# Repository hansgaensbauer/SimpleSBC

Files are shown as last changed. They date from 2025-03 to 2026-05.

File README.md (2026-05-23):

# SimpleSBC
A simple, open source SBC built around the STM32MP1

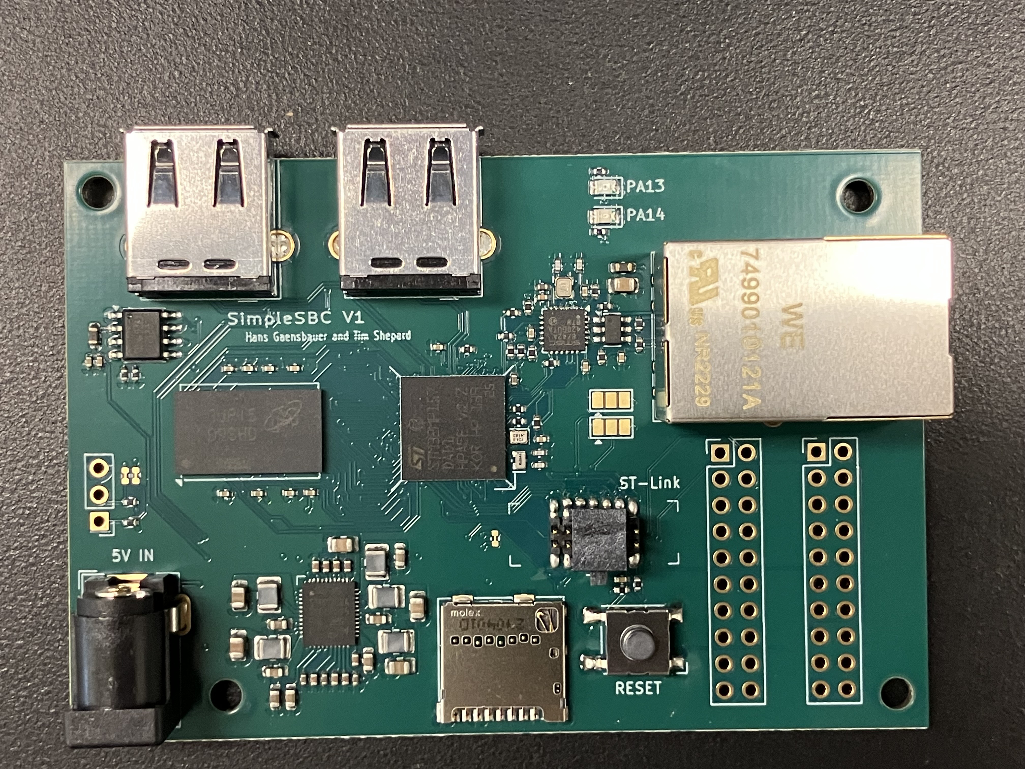
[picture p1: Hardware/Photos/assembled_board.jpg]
A photo of the assembled board


## Getting Started
1. `git clone` this repository
2. Run `git submodule init` and `git submodule update --recursive` to get Yocto and layers
3. Install dependencies:
   ```
   sudo apt update
   sudo apt upgrade
   sudo apt install -y bc build-essential chrpath cpio diffstat gawk git texinfo wget gdisk python3 python3-pip
   ```
4. Run `source poky/oe-init-build-env build-simplesbc` to set up the environment
5. Run `bitbake custom-image` to build! This could take a while
6. After the build, use yocto\copy_sd.sh to set up an SD card. You may need to change the device name in the script.
7. Connect an ST-Link or other USB-Serial converter, and plug in power.
8. Enjoy linux! The default meta-custom layer includes python and some python libraries. 

## Related Projects
- [Linux-Keyer](https://github.com/hansgaensbauer/Linux-Keyer/tree/main): A real-time linux based CW keyer built around SimpleSBC

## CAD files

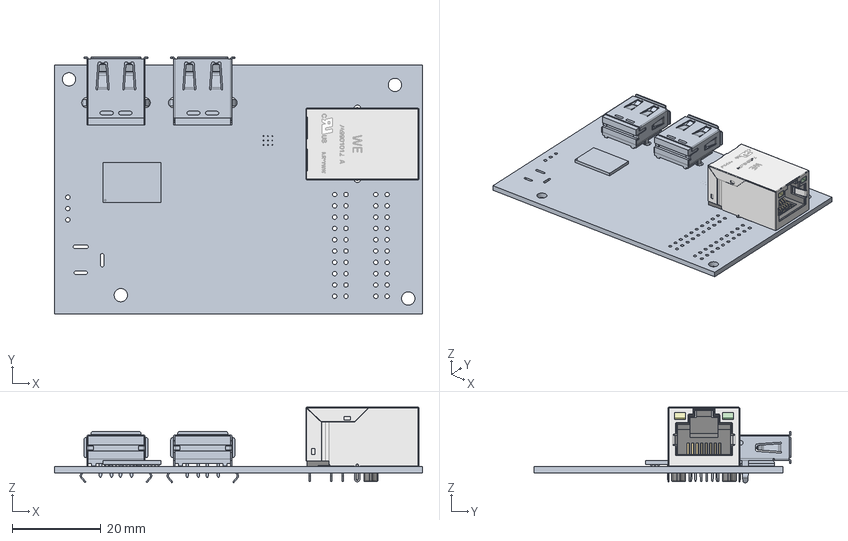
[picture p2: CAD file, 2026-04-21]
Hardware/simpleSBC.step
82.7 x 57.8 x 17.0 mm
USB_A_Molex_67643_Horizontal x 2
BGA-96_9.0x13.0mm_Layout2x3x16_P0.8mm
simpleSBC_PCB

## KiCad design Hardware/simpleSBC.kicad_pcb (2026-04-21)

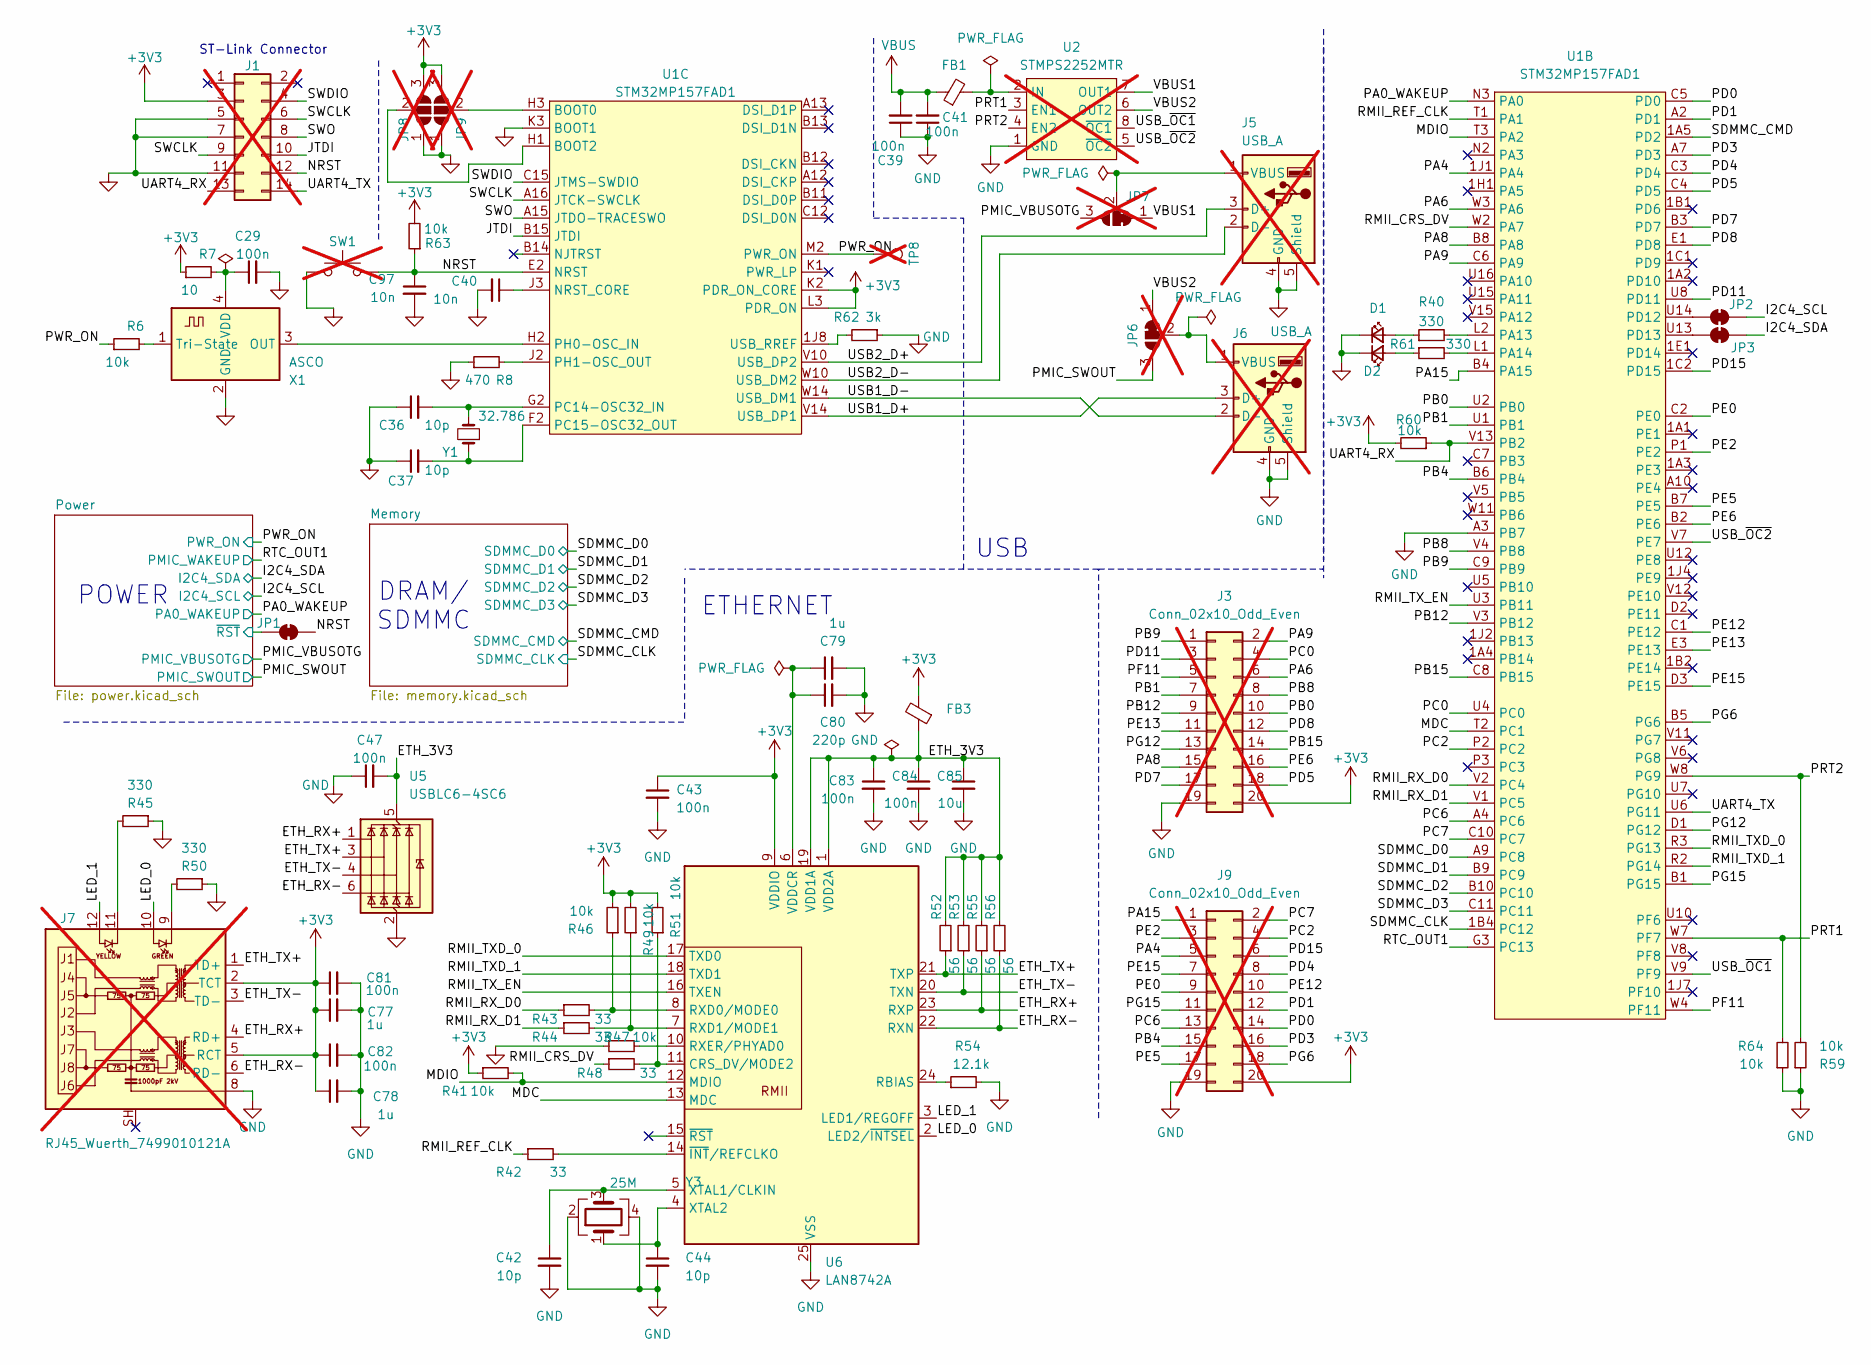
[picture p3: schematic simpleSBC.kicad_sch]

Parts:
C29, C39, C41, C43, C47, C81, C82, C83, C84: 100n; C_0402_1005Metric; JLCPCB Part # C1525
C36, C37, C42, C44: 10p; C_0402_1005Metric; JLCPCB Part # C32949
C40, C97: 10n; C_0402_1005Metric; JLCPCB Part # C15195
C77, C78, C79: 1u; C_0402_1005Metric; JLCPCB Part # C52923
C80: 220p; C_0402_1005Metric; JLCPCB Part # C1530
C85: 10u; C_0805_2012Metric; JLCPCB Part # C15850
D1: LED_Small; LED_0805_2012Metric; JLCPCB Part # C2296
D2: LED_Small; LED_0805_2012Metric; JLCPCB Part # C2297
FB1, FB3: FerriteBead_Small; L_0603_1608Metric; JLCPCB Part # C1002
J1: Conn_02x07_Odd_Even; PinHeader_2x7_P1.27mm_SMD; not fitted
J3, J9: Conn_02x10_Odd_Even; PinHeader_2x10_P2.54mm_Vertical; not fitted
J5, J6: USB_A; USB_A_Molex_67643_Horizontal; not fitted
J7: RJ45_Wuerth_7499010121A; RJ45_Wuerth_7499010121A_Horizontal; not fitted
JP1, JP2, JP3: SolderJumper_2_Bridged; Jumper_0402_Short
JP6, JP7: SolderJumper_3_Bridged12; SolderJumper-3_P1.3mm_Bridged2Bar12_Pad1.0x1.5mm; not fitted
JP8, JP9: SolderJumper_3_Open; SolderJumper-3_P1.3mm_Open_Pad1.0x1.5mm; not fitted
R6, R41, R46, R47, R49, R51, R59, R60, R63, R64: 10k; R_0402_1005Metric; JLCPCB Part # C25744
R7: 10; R_0402_1005Metric; JLCPCB Part # C25077
R8: 470; R_0402_1005Metric; JLCPCB Part # C25117
R40, R45, R50, R61: 330; R_0402_1005Metric; JLCPCB Part # C25104
R42, R43, R44, R48: 33; R_0402_1005Metric; JLCPCB Part # C25105
R52, R53, R55, R56: 56; R_0402_1005Metric; JLCPCB Part # C25127
R54: 12.1k; R_0402_1005Metric; JLCPCB Part # C25863
R62: 3k; R_0402_1005Metric; JLCPCB Part # C881171
SW1: SW_Push; SW_SPST_Omron_B3FS-101xP; not fitted
TP8: TestPoint; TestPoint_Pad_D1.0mm; not fitted
U1: STM32MP157FAD1; TFBGA257; JLCPCB Part # C1236719
U2: STMPS2252MTR; SOIC-8_3.9x4.9mm_P1.27mm; JLCPCB Part # C2680426; not fitted
U5: USBLC6-4SC6; SOT-23-6; JLCPCB Part # C111212
U6: LAN8742A; VQFN-24-1EP_4x4mm_P0.5mm_EP2.5x2.5mm_ThermalVias; JLCPCB Part # C220794
X1: ASCO; Oscillator_SMD_Abracon_ASCO-4Pin_1.6x1.2mm; JLCPCB Part # C19078199
Y1: 32.786; Crystal_SMD_MicroCrystal_CM9V-T1A-2Pin_1.6x1.0mm; JLCPCB Part # C5341287
Y3: 25M; Crystal_2.00x1.60mm; MPN 402F2501XIAR; JLCPCB Part # C127895

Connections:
+3V3: C43.1, C77.1, C78.1, C81.1, C82.1, FB3.2, J1.3, J3.20, J7.2 (TCT), J7.5 (RCT), J9.20, JP8.3 (B), JP9.3 (B), R7.1, R41.1, R46.2, R49.2, R51.2, R60.2, R63.2, U1.K2 (PDR_ON_CORE), U1.L3 (PDR_ON), U6.9 (VDDIO); also elsewhere on the board
/ETH_3V3: C47.2, C83.1, C84.1, C85.1, FB3.1, R52.2, R53.2, R55.2, R56.2, U5.5 (VBUS), U6.1 (VDD2A), U6.19 (VDD1A)
/ETH_RX+: J7.4 (RD+), R55.1, U5.1 (I/O1), U6.23 (RXP)
/ETH_RX-: J7.6 (RD-), R56.1, U5.6 (I/O4), U6.22 (RXN)
/ETH_TX+: J7.1 (TD+), R52.1, U5.3 (I/O2), U6.21 (TXP)
/ETH_TX-: J7.3 (TD-), R53.1, U5.4 (I/O3), U6.20 (TXN)
/I2C4_SCL: JP2.2 (B); also elsewhere on the board
/I2C4_SDA: JP3.2 (B); also elsewhere on the board
/JTDI: J1.10, U1.B15 (JTDI)
/LED_0: J7.10, U6.2 (LED2/~INTSEL)
/LED_1: J7.12, U6.3 (LED1/REGOFF)
/MDC: U1.T2 (PC1), U6.13 (MDC)
/MDIO: R41.2, U1.T3 (PA2), U6.12 (MDIO)
/NRST: C97.1, J1.12, JP1.2 (B), R63.1, SW1.2, U1.E2 (NRST)
/PA0_WAKEUP: U1.N3 (PA0); also elsewhere on the board
/PA4: J9.5, U1.1J1 (PA4)
/PA6: J3.6, U1.W3 (PA6)
/PA8: J3.15, U1.B8 (PA8)
/PA9: J3.2, U1.C6 (PA9)
/PA15: J9.1, U1.B4 (PA15)
/PB0: J3.10, U1.U2 (PB0)
/PB1: J3.7, U1.U1 (PB1)
/PB4: J9.15, U1.B6 (PB4)
/PB8: J3.8, U1.V4 (PB8)
/PB9: J3.1, U1.C9 (PB9)
/PB12: J3.9, U1.V3 (PB12)
/PB15: J3.14, U1.C8 (PB15)
/PC0: J3.4, U1.U4 (PC0)
/PC2: J9.4, U1.P2 (PC2)
/PC6: J9.13, U1.A4 (PC6)
/PC7: J9.2, U1.C10 (PC7)
/PD0: J9.14, U1.C5 (PD0)
/PD1: J9.12, U1.A2 (PD1)
/PD3: J9.16, U1.A7 (PD3)
/PD4: J9.8, U1.C3 (PD4)
/PD5: J3.18, U1.C4 (PD5)
/PD7: J3.17, U1.B3 (PD7)
/PD8: J3.12, U1.E1 (PD8)
/PD11: J3.3, U1.U8 (PD11)
/PD15: J9.6, U1.1C2 (PD15)
/PE0: J9.9, U1.C2 (PE0)
/PE2: J9.3, U1.P1 (PE2)
/PE5: J9.17, U1.B7 (PE5)
/PE6: J3.16, U1.B2 (PE6)
/PE12: J9.10, U1.C1 (PE12)
/PE13: J3.11, U1.E3 (PE13)
/PE15: J9.7, U1.D3 (PE15)
/PF11: J3.5, U1.W4 (PF11)
/PG6: J9.18, U1.B5 (PG6)
/PG12: J3.13, U1.D1 (PG12)
/PG15: J9.11, U1.B1 (PG15)
/PMIC_SWOUT: JP6.3 (B); also elsewhere on the board
/PMIC_VBUSOTG: JP7.3 (B); also elsewhere on the board
/PRT1: R64.2, U1.W7 (PF7), U2.3 (EN1)
/PRT2: R59.2, U1.W8 (PG9), U2.4 (EN2)
/PWR_ON: R6.1, TP8.1, U1.M2 (PWR_ON); also elsewhere on the board
/Power/~RST: JP1.1 (A); also elsewhere on the board
/RMII_CRS_DV: R48.1, U1.W2 (PA7)
/RMII_REF_CLK: R42.1, U1.T1 (PA1)
/RMII_RX_D0: R43.1, U1.V2 (PC4)
/RMII_RX_D1: R44.1, U1.V1 (PC5)
/RMII_TXD_0: U1.R3 (PG13), U6.17 (TXD0)
/RMII_TXD_1: U1.R2 (PG14), U6.18 (TXD1)
/RMII_TX_EN: U1.U3 (PB11), U6.16 (TXEN)
/RTC_OUT1: U1.G3 (PC13); also elsewhere on the board
/SDMMC_CLK: U1.1B4 (PC12); also elsewhere on the board
/SDMMC_CMD: U1.1A5 (PD2); also elsewhere on the board
/SDMMC_D0: U1.A9 (PC8); also elsewhere on the board
/SDMMC_D1: U1.B9 (PC9); also elsewhere on the board
/SDMMC_D2: U1.B10 (PC10); also elsewhere on the board
/SDMMC_D3: U1.C11; also elsewhere on the board
/SWCLK: J1.6, J1.9, U1.A16 (JTCK-SWCLK)
/SWDIO: J1.4, U1.C15 (JTMS-SWDIO)
/SWO: J1.8, U1.A15 (JTDO-TRACESWO)
/UART4_RX: J1.13, R60.1, U1.V13 (PB2)
/UART4_TX: J1.14, U1.U6 (PG11)
/USB1_D+: J6.3 (D+), U1.V14 (USB_DP1)
/USB1_D-: J6.2 (D-), U1.W14 (USB_DM1)
/USB2_D+: J5.3 (D+), U1.V10 (USB_DP2)
/USB2_D-: J5.2 (D-), U1.W10 (USB_DM2)
/USB_~OC1: U1.V9 (PF9), U2.8 (~OC1)
/USB_~OC2: U1.V7 (PE7), U2.5 (~OC2)
/VBUS1: JP7.1 (A), U2.7 (OUT1)
/VBUS2: JP6.1 (A), U2.6 (OUT2)
GND: C29.2, C36.1, C37.1, C39.1, C40.2, C41.1, C42.2, C43.2, C44.2, C47.1, C77.2, C78.2, C79.2, C80.2, C81.2, C82.2, C83.2, C84.2, C85.2, C97.2, D1.1 (K), D2.1 (K), J1.5, J1.7, J1.11, J3.19, J5.4 (GND), J5.5 (Shield), J6.4 (GND), J6.5 (Shield), J7.8, J9.19, JP8.1 (A), JP9.1 (A), R8.1, R45.1, R47.1, R50.1, R54.2, R59.1, R62.1, R64.1, SW1.1, U1.A3 (PB7), U1.K3 (BOOT1), U2.1 (GND), U5.2 (GND), U6.25 (VSS), X1.2 (GND), Y3.2, Y3.4; also elsewhere on the board
unnamed: D1.2 (A), R40.1
unnamed: D2.2 (A), R61.1
unnamed: J5.1 (VBUS), JP7.2 (C)
unnamed: J6.1 (VBUS), JP6.2 (C)
unnamed: J7.9, R50.2
unnamed: J7.11, R45.2
unnamed: JP2.1 (A), U1.U14 (PD12)
unnamed: JP3.1 (A), U1.U13 (PD13)
unnamed: JP8.2 (C), U1.H1 (BOOT2)
unnamed: JP9.2 (C), U1.H3 (BOOT0)
unnamed: R40.2, U1.L2 (PA13)
unnamed: R61.2, U1.L1 (PA14)
unnamed: C40.1, U1.J3 (NRST_CORE)
unnamed: C36.2, U1.G2 (PC14-OSC32_IN), Y1.2
unnamed: C37.2, U1.F2 (PC15-OSC32_OUT), Y1.1
unnamed: U1.H2 (PH0-OSC_IN), X1.3 (OUT)
unnamed: R8.2, U1.J2 (PH1-OSC_OUT)
unnamed: R62.2, U1.1J8 (USB_RREF)
unnamed: FB1.2, U2.2 (IN)
unnamed: R48.2, R51.1, U6.11 (CRS_DV/MODE2)
unnamed: R54.1, U6.24 (RBIAS)
unnamed: R43.2, R46.1, U6.8 (RXD0/MODE0)
unnamed: R44.2, R49.1, U6.7 (RXD1/MODE1)
unnamed: R47.2, U6.10 (RXER/PHYAD0)
unnamed: C79.1, C80.1, U6.6 (VDDCR)
unnamed: C42.1, U6.5 (XTAL1/CLKIN), Y3.3
unnamed: C44.1, U6.4 (XTAL2), Y3.1
unnamed: R42.2, U6.14 (~INT/REFCLKO)
unnamed: R6.2, X1.1 (Tri-State)
unnamed: C29.1, R7.2, X1.4 (VDD)
VBUS: C39.2, C41.2, FB1.1; also elsewhere on the board

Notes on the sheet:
USB
DRAM/ SDMMC
POWER
ETHERNET
ST-Link Connector

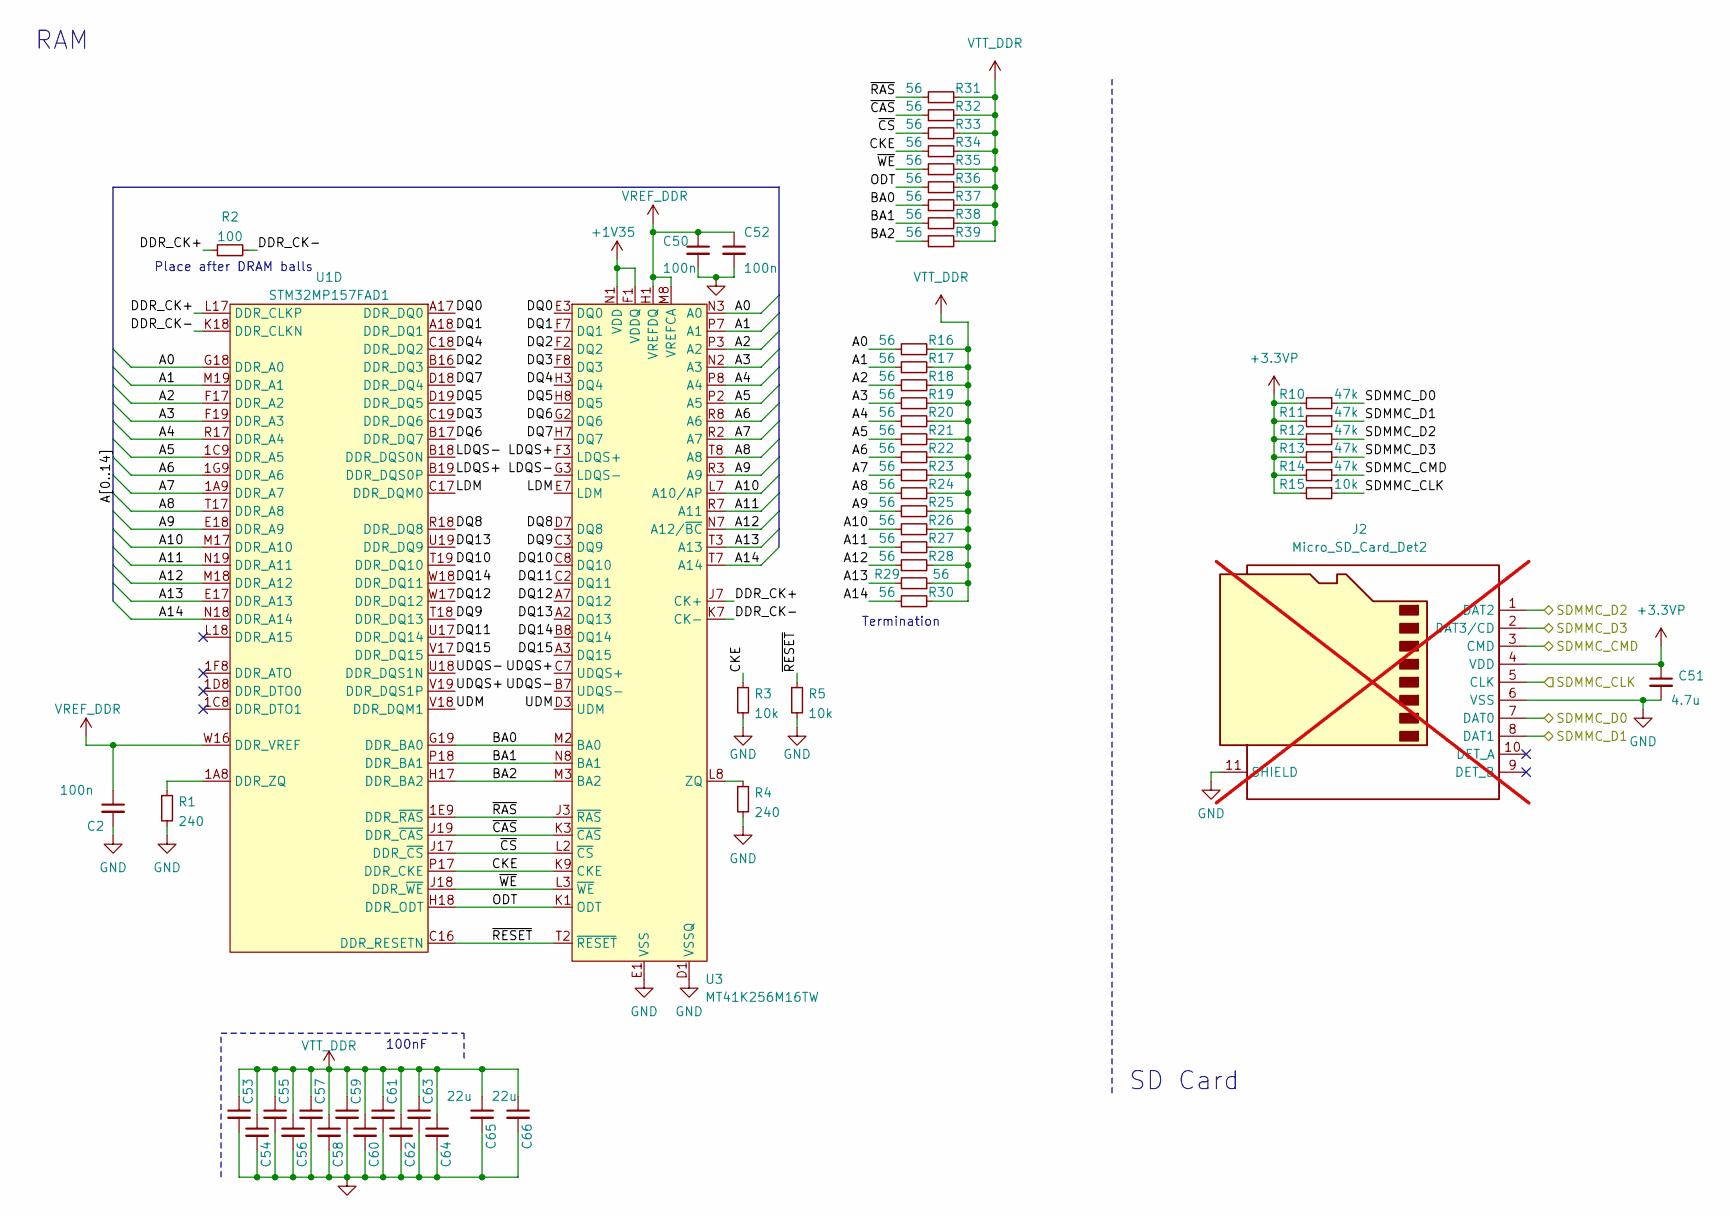
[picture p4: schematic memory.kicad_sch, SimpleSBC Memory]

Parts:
C2, C50, C52, C53, C54, C55, C56, C57, C58, C59, C60, C61, C62, C63, C64: 100n; C_0402_1005Metric; JLCPCB Part # C1525
C51: 4.7u; C_0402_1005Metric; JLCPCB Part # C23733
C65, C66: 22u; C_0805_2012Metric; JLCPCB Part # C45783
J2: Micro_SD_Card_Det2; microSD_HC_Molex_104031-0811; not fitted
R1, R4: 240; R_0402_1005Metric; JLCPCB Part # C208835
R2: 100; R_0402_1005Metric; JLCPCB Part # C25076
R3, R5, R15: 10k; R_0402_1005Metric; JLCPCB Part # C25744
R10, R11, R12, R13, R14: 47k; R_0402_1005Metric; JLCPCB Part # C25792
R16, R17, R18, R19, R20, R21, R22, R23, R24, R25, R26, R27, R28, R29, R30, R31, R32, R33, R34, R35, R36, R37, R38, R39: 56; R_0402_1005Metric; JLCPCB Part # C25127
U1: STM32MP157FAD1; TFBGA257; JLCPCB Part # C1236719
U3: MT41K256M16TW; BGA-96_9.0x13.0mm_Layout2x3x16_P0.8mm; JLCPCB Part # C253882

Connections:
+1V35: U3.A1 (VDDQ), U3.A8 (VDDQ), U3.B2 (VDD), U3.C1 (VDDQ), U3.C9 (VDDQ), U3.D2 (VDDQ), U3.D9 (VDD), U3.E9 (VDDQ), U3.F1 (VDDQ), U3.G7 (VDD), U3.H2 (VDDQ), U3.H9 (VDDQ), U3.K2 (VDD), U3.K8 (VDD), U3.N1 (VDD), U3.N9 (VDD), U3.R1 (VDD), U3.R9 (VDD); also elsewhere on the board
+3.3VP: C51.1, J2.4 (VDD), R10.2, R11.2, R12.2, R13.2, R14.2, R15.2; also elsewhere on the board
/Memory/A0: R16.1, U1.G18 (DDR_A0), U3.N3 (A0)
/Memory/A1: R17.1, U1.M19 (DDR_A1), U3.P7 (A1)
/Memory/A2: R18.1, U1.F17 (DDR_A2), U3.P3 (A2)
/Memory/A3: R19.1, U1.F19 (DDR_A3), U3.N2 (A3)
/Memory/A4: R20.1, U1.R17 (DDR_A4), U3.P8 (A4)
/Memory/A5: R21.1, U1.1C9 (DDR_A5), U3.P2 (A5)
/Memory/A6: R22.1, U1.1G9 (DDR_A6), U3.R8 (A6)
/Memory/A7: R23.1, U1.1A9 (DDR_A7), U3.R2 (A7)
/Memory/A8: R24.1, U1.T17 (DDR_A8), U3.T8 (A8)
/Memory/A9: R25.1, U1.E18 (DDR_A9), U3.R3 (A9)
/Memory/A10: R26.1, U1.M17 (DDR_A10), U3.L7 (A10/AP)
/Memory/A11: R27.1, U1.N19 (DDR_A11), U3.R7 (A11)
/Memory/A12: R28.1, U1.M18 (DDR_A12), U3.N7 (A12/~BC)
/Memory/A13: R29.2, U1.E17 (DDR_A13), U3.T3 (A13)
/Memory/A14: R30.1, U1.N18 (DDR_A14), U3.T7 (A14)
/Memory/BA0: R37.1, U1.G19 (DDR_BA0), U3.M2 (BA0)
/Memory/BA1: R38.1, U1.P18 (DDR_BA1), U3.N8 (BA1)
/Memory/BA2: R39.1, U1.H17 (DDR_BA2), U3.M3 (BA2)
/Memory/CKE: R3.1, R34.1, U1.P17 (DDR_CKE), U3.K9 (CKE)
/Memory/DDR_CK+: R2.1, U1.L17 (DDR_CLKP), U3.J7 (CK+)
/Memory/DDR_CK-: R2.2, U1.K18 (DDR_CLKN), U3.K7 (CK-)
/Memory/DQ0: U1.A17 (DDR_DQ0), U3.E3 (DQ0)
/Memory/DQ1: U1.A18 (DDR_DQ1), U3.F7 (DQ1)
/Memory/DQ2: U1.B16 (DDR_DQ3), U3.F2 (DQ2)
/Memory/DQ3: U1.C19 (DDR_DQ6), U3.F8 (DQ3)
/Memory/DQ4: U1.C18 (DDR_DQ2), U3.H3 (DQ4)
/Memory/DQ5: U1.D19 (DDR_DQ5), U3.H8 (DQ5)
/Memory/DQ6: U1.B17 (DDR_DQ7), U3.G2 (DQ6)
/Memory/DQ7: U1.D18 (DDR_DQ4), U3.H7 (DQ7)
/Memory/DQ8: U1.R18 (DDR_DQ8), U3.D7 (DQ8)
/Memory/DQ9: U1.T18 (DDR_DQ13), U3.C3 (DQ9)
/Memory/DQ10: U1.T19 (DDR_DQ10), U3.C8 (DQ10)
/Memory/DQ11: U1.U17 (DDR_DQ14), U3.C2 (DQ11)
/Memory/DQ12: U1.W17 (DDR_DQ12), U3.A7 (DQ12)
/Memory/DQ13: U1.U19 (DDR_DQ9), U3.A2 (DQ13)
/Memory/DQ14: U1.W18 (DDR_DQ11), U3.B8 (DQ14)
/Memory/DQ15: U1.V17 (DDR_DQ15), U3.A3 (DQ15)
/Memory/LDM: U1.C17 (DDR_DQM0), U3.E7 (LDM)
/Memory/LDQS+: U1.B19 (DDR_DQS0P), U3.F3 (LDQS+)
/Memory/LDQS-: U1.B18 (DDR_DQS0N), U3.G3 (LDQS-)
/Memory/ODT: R36.1, U1.H18 (DDR_ODT), U3.K1 (ODT)
/Memory/UDM: U1.V18 (DDR_DQM1), U3.D3 (UDM)
/Memory/UDQS+: U1.V19 (DDR_DQS1P), U3.C7 (UDQS+)
/Memory/UDQS-: U1.U18 (DDR_DQS1N), U3.B7 (UDQS-)
/Memory/~CAS: R32.1, U1.J19 (DDR_~CAS), U3.K3 (~CAS)
/Memory/~CS: R33.1, U1.J17 (DDR_~CS), U3.L2 (~CS)
/Memory/~RAS: R31.1, U1.1E9 (DDR_~RAS), U3.J3 (~RAS)
/Memory/~RESET: R5.1, U1.C16 (DDR_RESETN), U3.T2 (~RESET)
/Memory/~WE: R35.1, U1.J18 (DDR_~WE), U3.L3 (~WE)
/SDMMC_CLK: J2.5 (CLK), R15.1; also elsewhere on the board
/SDMMC_CMD: J2.3 (CMD), R14.1; also elsewhere on the board
/SDMMC_D0: J2.7 (DAT0), R10.1; also elsewhere on the board
/SDMMC_D1: J2.8 (DAT1), R11.1; also elsewhere on the board
/SDMMC_D2: J2.1 (DAT2), R12.1; also elsewhere on the board
/SDMMC_D3: J2.2 (DAT3/CD), R13.1; also elsewhere on the board
GND: C2.2, C50.2, C51.2, C52.2, C53.2, C54.2, C55.2, C56.2, C57.2, C58.2, C59.2, C60.2, C61.2, C62.2, C63.2, C64.2, C65.2, C66.2, J2.6 (VSS), J2.11 (SHIELD), R1.2, R3.2, R4.2, R5.2, U3.A9 (VSS), U3.B1 (VSSQ), U3.B3 (VSS), U3.B9 (VSSQ), U3.D1 (VSSQ), U3.D8 (VSSQ), U3.E1 (VSS), U3.E2 (VSSQ), U3.E8 (VSSQ), U3.F9 (VSSQ), U3.G1 (VSSQ), U3.G8 (VSS), U3.G9 (VSSQ), U3.J2 (VSS), U3.J8 (VSS), U3.M1 (VSS), U3.M9 (VSS), U3.P1 (VSS), U3.P9 (VSS), U3.T1 (VSS), U3.T9 (VSS); also elsewhere on the board
unnamed: R1.1, U1.1A8 (DDR_ZQ)
unnamed: R4.1, U3.L8 (ZQ)
VREF_DDR: C2.1, C50.1, C52.1, U1.W16 (DDR_VREF), U3.H1 (VREFDQ), U3.M8 (VREFCA); also elsewhere on the board
VTT_DDR: C53.1, C54.1, C55.1, C56.1, C57.1, C58.1, C59.1, C60.1, C61.1, C62.1, C63.1, C64.1, C65.1, C66.1, R16.2, R17.2, R18.2, R19.2, R20.2, R21.2, R22.2, R23.2, R24.2, R25.2, R26.2, R27.2, R28.2, R29.1, R30.2, R31.2, R32.2, R33.2, R34.2, R35.2, R36.2, R37.2, R38.2, R39.2; also elsewhere on the board

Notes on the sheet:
RAM
SD Card
100nF
Place after DRAM balls
Termination

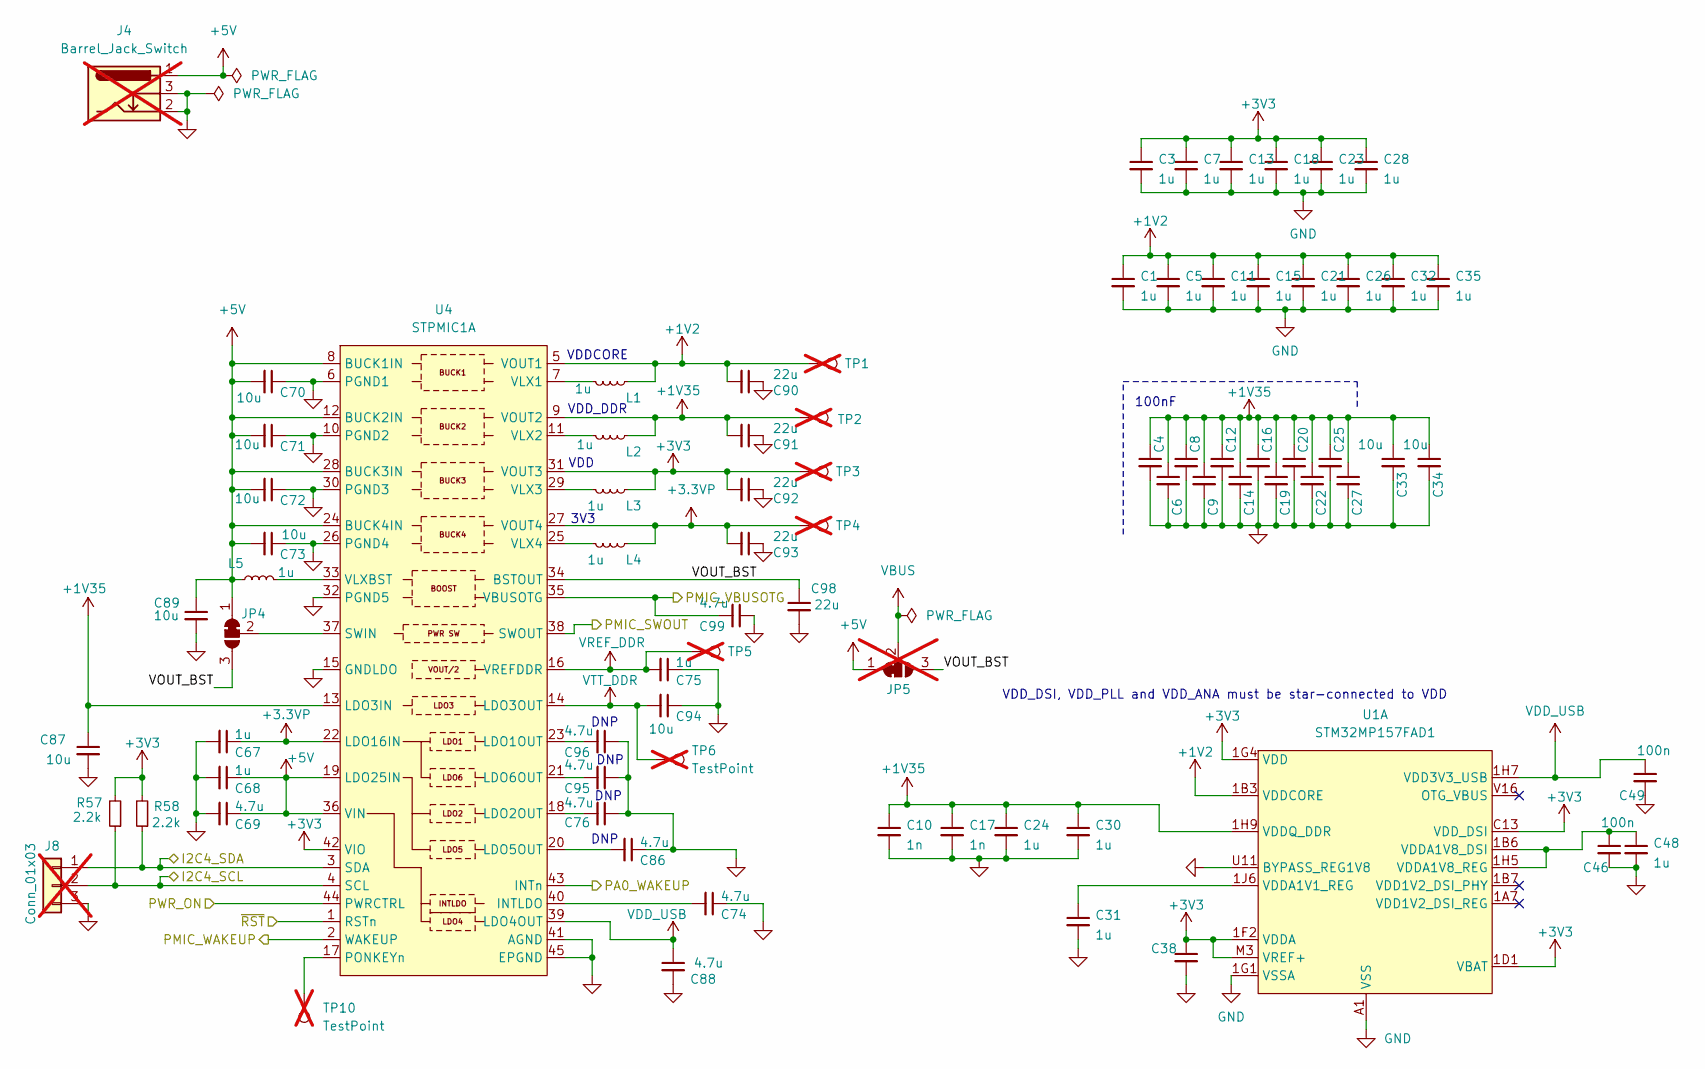
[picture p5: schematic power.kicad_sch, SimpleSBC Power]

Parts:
C1, C3, C5, C7, C11, C13, C15, C18, C21, C23, C24, C26, C28, C30, C31, C32, C35, C38, C48, C67, C68, C75: 1u; C_0402_1005Metric; JLCPCB Part # C52923
C4, C6, C8, C9, C12, C14, C16, C19, C20, C22, C25, C27, C46, C49: 100n; C_0402_1005Metric; JLCPCB Part # C1525
C10, C17: 1n; C_0402_1005Metric; JLCPCB Part # C1523
C33, C34: 10u; C_0805_2012Metric; JLCPCB Part # C15850
C69, C74, C76, C86, C88, C95, C96, C99: 4.7u; C_0402_1005Metric; JLCPCB Part # C23733
C70, C71, C72, C73, C87, C89, C94: 10u; C_0603_1608Metric; JLCPCB Part # C19702
C90, C91, C92, C93, C98: 22u; C_0805_2012Metric; JLCPCB Part # C45783
J4: Barrel_Jack_Switch; BarrelJack_Wuerth_6941xx301002; not fitted
J8: Conn_01x03; PinHeader_1x03_P2.54mm_Vertical; not fitted
JP4: SolderJumper_3_Bridged12; SolderJumper-3_P1.3mm_Bridged2Bar12_Pad1.0x1.5mm
JP5: SolderJumper_3_Bridged12; SolderJumper-3_P1.3mm_Bridged2Bar12_Pad1.0x1.5mm; not fitted
L1, L2, L3, L4, L5: 1u; L_1008_2520Metric; JLCPCB Part # C76795
R57, R58: 2.2k; R_0402_1005Metric; JLCPCB Part # C25879
TP1, TP2, TP3, TP4, TP5, TP6, TP10: TestPoint; TestPoint_Pad_D1.0mm; not fitted
U1: STM32MP157FAD1; TFBGA257; JLCPCB Part # C1236719
U4: STPMIC1A; WFQFN44L; JLCPCB Part # C2156050

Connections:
+1V2: C1.1, C5.1, C11.1, C15.1, C21.1, C26.1, C32.1, C35.1, C90.2, L1.2, TP1.1, U1.1B3 (VDDCORE), U1.1B5 (VDDCORE), U1.1C4 (VDDCORE), U1.1C6 (VDDCORE), U1.1D3 (VDDCORE), U1.1D5 (VDDCORE), U1.1D7 (VDDCORE), U1.1E4 (VDDCORE), U1.1E6 (VDDCORE), U1.1E8 (VDDCORE), U1.1F5 (VDDCORE), U1.1F7 (VDDCORE), U1.1G6 (VDDCORE), U1.1G8 (VDDCORE), U4.5 (VOUT1)
+1V35: C4.1, C6.1, C8.1, C9.1, C10.1, C12.1, C14.1, C16.1, C17.1, C19.1, C20.1, C22.1, C24.1, C25.1, C27.1, C30.1, C33.1, C34.1, C87.1, C91.2, L2.2, TP2.1, U1.1B9 (VDDQ_DDR), U1.1D9 (VDDQ_DDR), U1.1F9 (VDDQ_DDR), U1.1H9 (VDDQ_DDR), U4.9 (VOUT2), U4.13 (LDO3IN); also elsewhere on the board
+3.3VP: C67.1, C93.2, L4.2, TP4.1, U4.22 (LDO16IN), U4.27 (VOUT4); also elsewhere on the board
+3V3: C3.1, C7.1, C13.1, C18.1, C23.1, C28.1, C38.1, C92.2, L3.2, R57.2, R58.2, TP3.1, U1.1D1 (VBAT), U1.1E2 (VDD), U1.1F1 (VDDA), U1.1F2 (VDDA), U1.1F3 (VDD), U1.1G3 (VDD), U1.1G4 (VDD), U1.1J3 (VDD), U1.C13 (VDD_DSI), U1.M3 (VREF+), U4.31 (VOUT3), U4.42 (VIO); also elsewhere on the board
+5V: C68.1, C69.1, C70.2, C71.2, C72.2, C73.2, C89.1, J4.1, JP4.1 (A), JP5.1 (A), L5.2, U4.8 (BUCK1IN), U4.12 (BUCK2IN), U4.19 (LDO25IN), U4.24 (BUCK4IN), U4.28 (BUCK3IN), U4.36 (VIN)
/I2C4_SCL: J8.2, R57.1, U4.4 (SCL); also elsewhere on the board
/I2C4_SDA: J8.1, R58.1, U4.3 (SDA); also elsewhere on the board
/PA0_WAKEUP: U4.43 (INTn); also elsewhere on the board
/PMIC_SWOUT: U4.38 (SWOUT); also elsewhere on the board
/PMIC_VBUSOTG: C99.2, U4.35 (VBUSOTG); also elsewhere on the board
/PWR_ON: U4.44 (PWRCTRL); also elsewhere on the board
/Power/VOUT_BST: C98.1, JP4.3 (B), JP5.3 (B), U4.34 (BSTOUT)
/Power/~RST: U4.1 (RSTn); also elsewhere on the board
/RTC_OUT1: U4.2 (WAKEUP); also elsewhere on the board
GND: C1.2, C3.2, C4.2, C5.2, C6.2, C7.2, C8.2, C9.2, C10.2, C11.2, C12.2, C13.2, C14.2, C15.2, C16.2, C17.2, C18.2, C19.2, C20.2, C21.2, C22.2, C23.2, C24.2, C25.2, C26.2, C27.2, C28.2, C30.2, C31.2, C32.2, C33.2, C34.2, C35.2, C38.2, C46.2, C48.2, C49.2, C67.2, C68.2, C69.2, C70.1, C71.1, C72.1, C73.1, C74.1, C75.1, C76.1, C86.1, C87.2, C88.2, C89.2, C90.1, C91.1, C92.1, C93.1, C94.1, C95.1, C96.1, C98.2, C99.1, J4.2, J4.3, J8.3, U1.1A6 (VSS), U1.1B8 (VSS), U1.1C3 (VSS), U1.1C5 (VSS), U1.1C7 (VSS), U1.1D2 (VSS), U1.1D4 (VSS), U1.1D6 (VSS), U1.1E3 (VSS), U1.1E5 (VSS), U1.1E7 (VSS), U1.1F4 (VSS), U1.1F6 (VSS), U1.1G1 (VSSA), U1.1G2 (VSS), U1.1G5 (VSS), U1.1G7 (VSS), U1.1H2 (VSS), U1.1H3 (VSS), U1.1H4 (VSS), U1.1H6 (VSS), U1.1H8 (VSS), U1.1J5 (VSS), U1.1J9 (VSS), U1.A1 (VSS), U1.A6 (VSS), U1.A19 (VSS), U1.C14 (VSS), U1.D17 (VSS), U1.F3 (VSS), U1.F18 (VSS), U1.G1 (VSS), U1.G17 (VSS), U1.K17 (VSS), U1.K19 (VSS), U1.N1 (VSS), U1.N17 (VSS), U1.R19 (VSS), U1.U9 (VSS), U1.U11 (BYPASS_REG1V8), U1.W1 (VSS), U1.W5 (VSS), U1.W13 (VSS), U1.W19 (VSS), U4.6 (PGND1), U4.10 (PGND2), U4.15 (GNDLDO), U4.26 (PGND4), U4.30 (PGND3), U4.32 (PGND5), U4.41 (AGND), U4.45 (EPGND); also elsewhere on the board
unnamed: JP4.2 (C), U4.37 (SWIN)
unnamed: C31.1, U1.1J6 (VDDA1V1_REG)
unnamed: C46.1, C48.1, U1.1B6 (VDDA1V8_DSI), U1.1H5 (VDDA1V8_REG)
unnamed: C74.2, U4.40 (INTLDO)
unnamed: C96.2, U4.23 (LDO1OUT)
unnamed: C76.2, U4.18 (LDO2OUT)
unnamed: C86.2, U4.20 (LDO5OUT)
unnamed: C95.2, U4.21 (LDO6OUT)
unnamed: TP10.1, U4.17 (PONKEYn)
unnamed: L1.1, U4.7 (VLX1)
unnamed: L2.1, U4.11 (VLX2)
unnamed: L3.1, U4.29 (VLX3)
unnamed: L4.1, U4.25 (VLX4)
unnamed: L5.1, U4.33 (VLXBST)
VBUS: JP5.2 (C); also elsewhere on the board
VDD_USB: C49.1, C88.1, U1.1H7 (VDD3V3_USB), U4.39 (LDO4OUT)
VREF_DDR: C75.2, TP5.1, U4.16 (VREFDDR); also elsewhere on the board
VTT_DDR: C94.2, TP6.1, U4.14 (LDO3OUT); also elsewhere on the board

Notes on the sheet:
VDD
DNP
VDDCORE
100nF
3V3
VDD_DDR
VDD_DSI, VDD_PLL and VDD_ANA must be star-connected to VDD

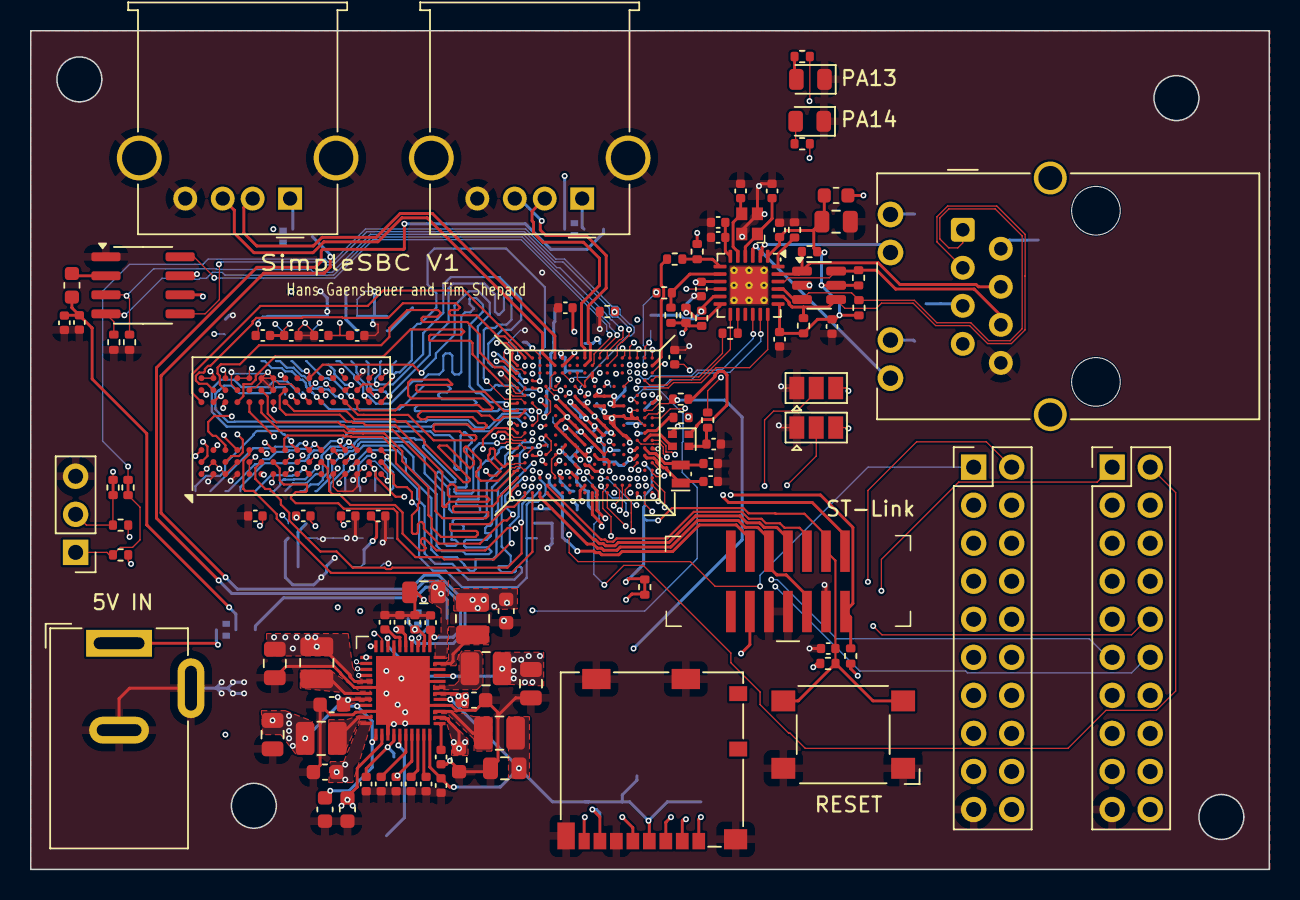
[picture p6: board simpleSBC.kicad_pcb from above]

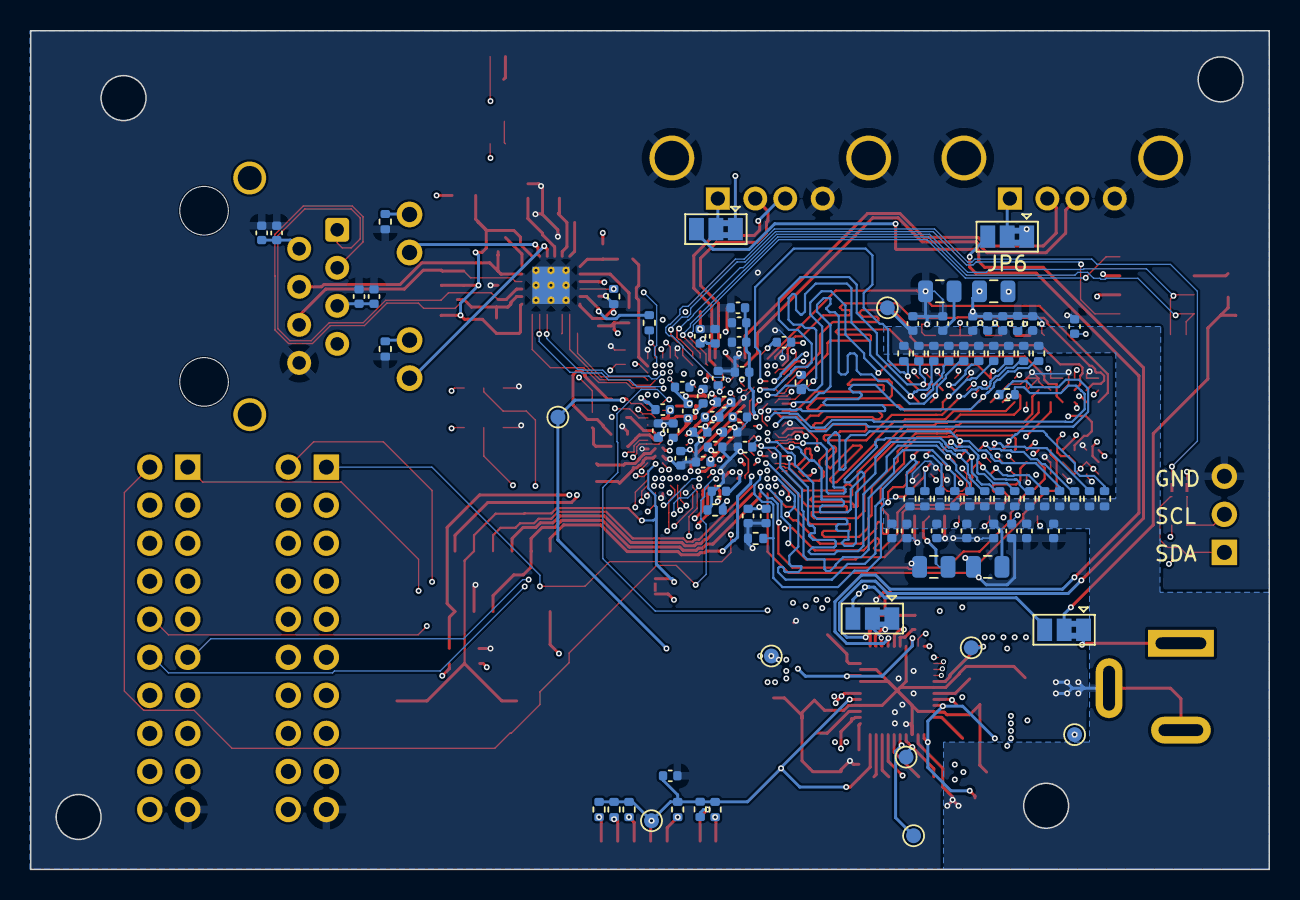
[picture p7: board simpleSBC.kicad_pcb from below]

Board: 6 copper layers, 82.7 x 56.0 mm, 206 parts (101 on the bottom side), 189 nets.

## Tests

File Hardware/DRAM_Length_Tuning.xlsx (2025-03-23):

Trace | Length
CK+ | 30.65
CK- | 30.64
A0 | 30.05
A1 | 29.96
A2 | 30.08
A3 | 29.98
A4 | 30.05
A5 | 30.04
A6 | 29.91
A7 | 29.83
A8 | 30.14
A9 | 29.86
A10 | 29.95
A11 | 29.85
A12 | 29.98
A13 | 29.92
A14 | 30.05
LDQS+ | 28.91
LDQS- | 28.91
LDM | 28.93
DQ0 | 29.04
DQ1 | 28.85
DQ2 | 29.16
DQ3 | 29.01
DQ4 | 28.93
DQ5 | 28.87
DQ6 | 29.08
DQ7 | 28.97
DQ8 | 29.06
DQ9 | 28.89
DQ10 | 29.06
DQ11 | 28.92
DQ12 | 29.03
DQ13 | 29.13
DQ14 | 29.09
DQ15 | 29.2
UDQS+ | 28.56
UDQS- | 28.56
UDM | 29
BA0 | 29.9
BA1 | 30.04
BA2 | 29.91
RASN | 29.86
CASN | 29.93
CSN | 29.93
CKE | 29.79
WEN | 29.86
ODT | 30.03

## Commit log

2022-06-21 Hardware: Add initial Hardware
    [simpleSBC.kicad_pcb, simpleSBC.kicad_sch]
2025-01-13 Add STPMIC1
    [simpleSBC.kicad_sch]
2025-02-03 Remove old files
    [memory.kicad_sch, power.kicad_sch, simpleSBC.kicad_pcb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]
2025-02-03 Create libraries and move custom symbols to project specific libraries
    [memory.kicad_sch, power.kicad_sch, simpleSBC.kicad_sch]
2025-02-04 First Draft schematic (R2)
    [memory.kicad_sch, power.kicad_sch, simpleSBC.kicad_pcb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]
2025-02-05 Add Ethernet and USB power switching
    [memory.kicad_sch, power.kicad_sch, simpleSBC.kicad_pcb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]
2025-02-05 Schematic symbol pin type fixes
    [memory.kicad_sch, power.kicad_sch, simpleSBC.kicad_sch]
2025-02-07 First pass through ST Design Checklist
    [memory.kicad_sch, power.kicad_sch, simpleSBC.kicad_pcb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]
2025-02-09 First Pass for Floorplanning
    [simpleSBC.kicad_pcb, simpleSBC.kicad_sch]
2025-03-06 First Pass Routing
    [memory.kicad_sch, power.kicad_sch, simpleSBC.kicad_pcb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]
2025-03-09 ERC/DRC Clean
    [memory.kicad_sch, power.kicad_sch, simpleSBC.kicad_pcb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]
2025-03-23 Redo DRAM Length Tuning
    [DRAM_Length_Tuning.xlsx, simpleSBC.kicad_pcb, simpleSBC.kicad_sch]
2025-03-23 Reconnect Nets after length tuning
    [DRAM_Length_Tuning.xlsx, simpleSBC.kicad_pcb, simpleSBC.kicad_sch]
2025-03-23 Add Boot selection jumpers
    [simpleSBC.kicad_pcb, simpleSBC.kicad_sch]
2025-03-24 Add USB enable pulldowns
    [power.kicad_sch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]
2025-03-24 Update .gitignore to remove cam
    [simpleSBC-B_Cu.gbr, simpleSBC-B_Mask.gbr, simpleSBC-B_Paste.gbr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]
2025-03-25 prepare for assembly
    [DRAM_Length_Tuning.xlsx, memory.kicad_sch, power.kicad_sch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]
2025-03-26 Default close jumpers and fix USB signal switching
    [simpleSBC.kicad_pcb, simpleSBC.kicad_sch]
2025-03-26 Don't track auto_saved_files
2025-07-12 submodule configuration
    [templateconf.cfg]
2025-07-15 update to scarthgap
    [templateconf.cfg]
2025-07-16 Custom device tree modifications
2025-07-19 Clean DSI from device tree
2025-07-19 remove references to eval board device trees
2026-04-21 Stale changes
    [simpleSBC.kicad_pcb, simpleSBC.kicad_sch, simpleSBC.step]
2026-06-28 add kicad history to gitignore
